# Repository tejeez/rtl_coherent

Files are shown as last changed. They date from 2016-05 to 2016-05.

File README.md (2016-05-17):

rtl_coherent: Synchronized RTL-SDR receivers
============================================

This is a hardware and software project to synchronize multiple RTL-SDR
receivers and make it possible to use them for applications such as
radio direction finding, passive radars, measuring equipment,
radio astronomy interferometers and MIMO communications.

Basic idea
----------

A single 28.8 MHz reference clock is distributed to all dongles. This makes
their sampling rates and local oscillator frequencies equal but doesn't
guarantee that they would actually sample simultaneously or that their
local oscillators would be in the same phase. 

Both the local oscillator phase and sample time offset get a random value
every time the dongles are initialized. This happens because commands don't
arrive to all receivers at exactly the same time and because their frequency
synthesizers are not known to provide a way to reset their phases.

To handle this we have to find the time and phase offsets every time the
receiver is used. This is done by disconnecting receivers from their antennas
and connecting them to a single white noise source. Cross correlating this
noise finds these offsets and lets us correct them. Currently the signal is
recorded in short blocks and each block starts with a burst of noise.

Electronics
-----------

The current hardware prototype has 3 dongles. One of them has the original
28.8 MHz crystal in place and other 2 dongles have the crystal removed. Clock
is distributed from one dongle to crystal pins of the two other dongles
through small capacitors. A better solution for a larger number of dongles
would be to have a separate 28.8 MHz oscillator and distribute it.

The inputs of the dongles are switched between antennas and noise source by
SA630D switches. They are controlled by an RC timing circuit triggered by
I2C clock in the dongles. Every time the R820T tuner chip receives a
command from the RTL2832U chip, there's some activity on the I2C bus.
This switches the inputs to the noise source and the timing circuit keeps
them there for some time after the I2C traffic has finished. The idea is to
have the noise burst triggered every time the center frequency is changed
which should make fast scanning easier.

A crude schematic of simple prototype hardware is now available in
[hardware/simple/](hardware/simple/README.md).

Software
--------

The current software is primarily written for radio direction finding based on
phase difference between elements of an antenna array.

The software records a block of signal from each dongle, cross correlates the
noise in beginning of each block to determine the phase and timing offsets,
corrects for them, divides the signal in narrow frequency bins using FFT and
calculates covariance between each receiver pair for each frequency bin.
Complex argument of an element in the covariance matrix represents the measured
phase difference between two antennas and is used for direction finding.
The same covariance matrix could also be used in more sophisticated direction
finding algorithms such as MUSIC or ESPRIT which might become more useful when
the number of antennas is increased.

rtl_coherent uses features in keenerd's experimental experimental RTL-SDR
branch. Get it from https://github.com/keenerd/rtl-sdr

The software has mostly been developed in Debian Linux on ordinary x86-64 PCs
but many other Linux distributions and architectures should work as well.

Experiments and demonstrations
------------------------------

Direction finding was first tested on 433 MHz amateur radio band using an array
of 3 groundplane antennas spaced by 1/3 wavelength.
See a video here: https://www.youtube.com/watch?v=8Wzb1mgZ0EE

It was also tested on higher HF bands using an array of ground mounted
vertical antennas. A spectrogram from 26.4 MHz to 28.8 MHz where color hue
represents the estimated angle of arrival can be seen here:
http://prkele.prk.tky.fi/~peltolt2/colordf_27600kHz_7h.jpg

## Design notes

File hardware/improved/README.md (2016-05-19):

Schematics and PCB designs for parts of improved hardware.
PCBs have been designed using eagle.

noisesource.sch is the schematic for a better noise source based on three
BGA2803 MMICs. This MMIC was chosen because it has almost flat gain up to
2 GHz, works on 3.3 V and consumes relatively little current. Linearity
and noise figure are not important here.

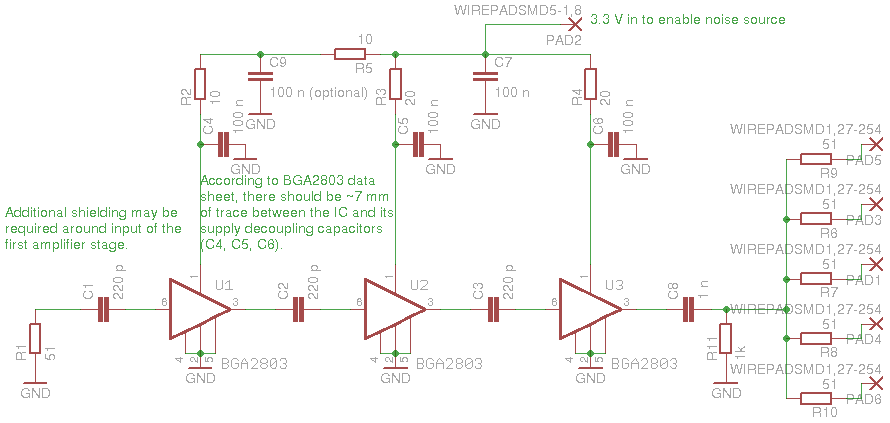
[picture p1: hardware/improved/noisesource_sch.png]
Schematic of noise source


noisesource.brd is a PCB design which has been built on a homemade PCB
and works. The positions of ground vias in the design don't exactly
correspond to what was built. Consider adding more vias near edge of the
board if you decide to order PCBs from somewhere.

The noise source hasn't been tested as a part of the coherent rtl-sdr setup
yet but it should work well and will be tested soon.

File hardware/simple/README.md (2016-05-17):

Hardware for three dongles
==========================

This is the simple hardware with 3 dongles that has been used for most of tests
for now.

One of the dongles has the original 28.8 MHz crystal in place and other 2
dongles have the crystal removed. Clock is distributed from one dongle to
crystal pins of the two other dongles through 10 pF capacitors:
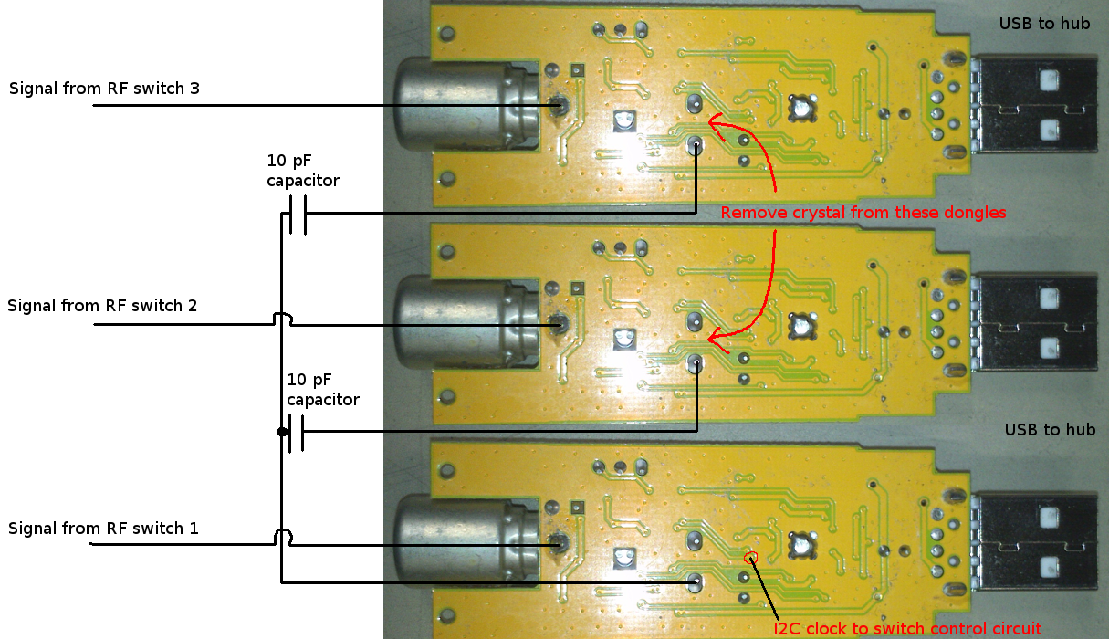
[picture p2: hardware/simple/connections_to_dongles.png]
Connections to dongles


The inputs of the dongles get signal through SA630D switches controlled by a
switch control circuit:
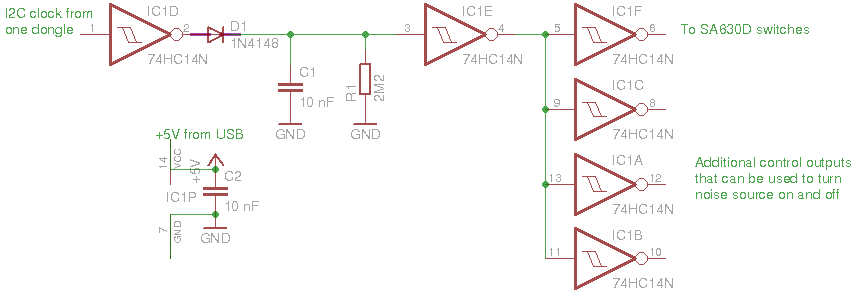
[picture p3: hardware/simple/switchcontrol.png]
Switch control circuit


Here's a schematic of the switch board:
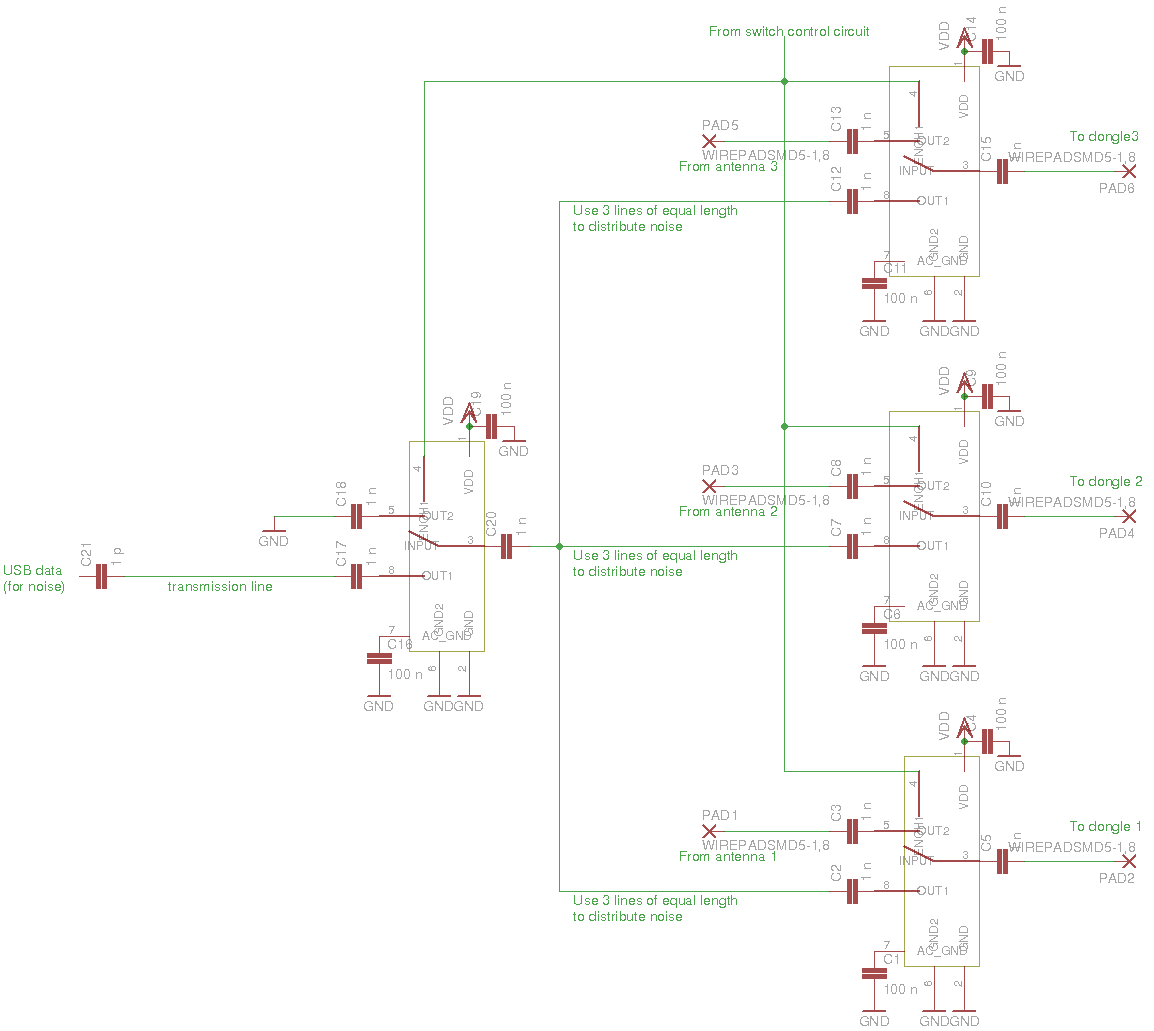
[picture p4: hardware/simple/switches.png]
Switches

(TODO: make it look more clear and learn to properly use some PCB design
software...)

One of USB data lines is used as the noise source.
It's not the best way but somewhat works.

Here's picture of the hardware to help understand how it's actually built:
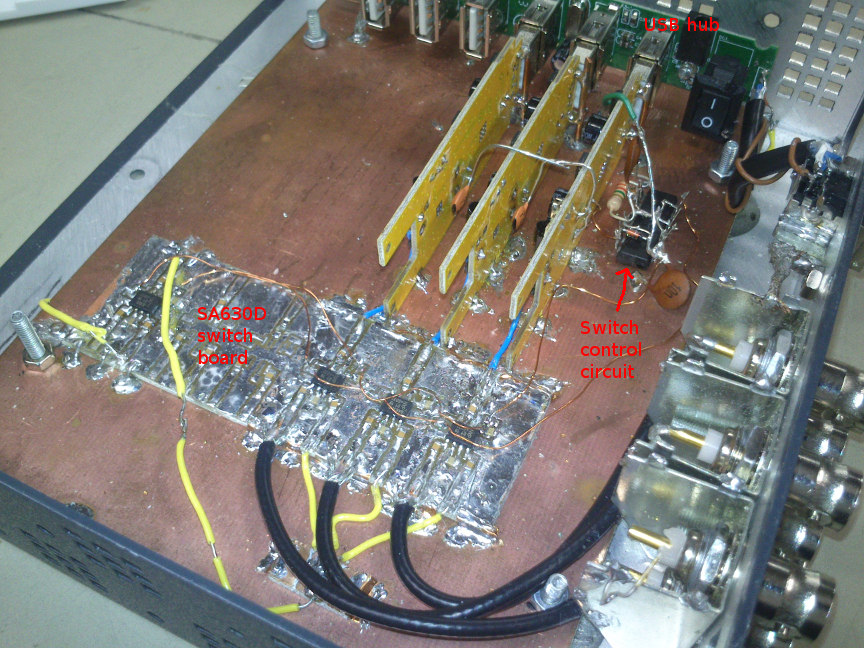
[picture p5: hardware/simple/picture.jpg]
Picture of the hardware


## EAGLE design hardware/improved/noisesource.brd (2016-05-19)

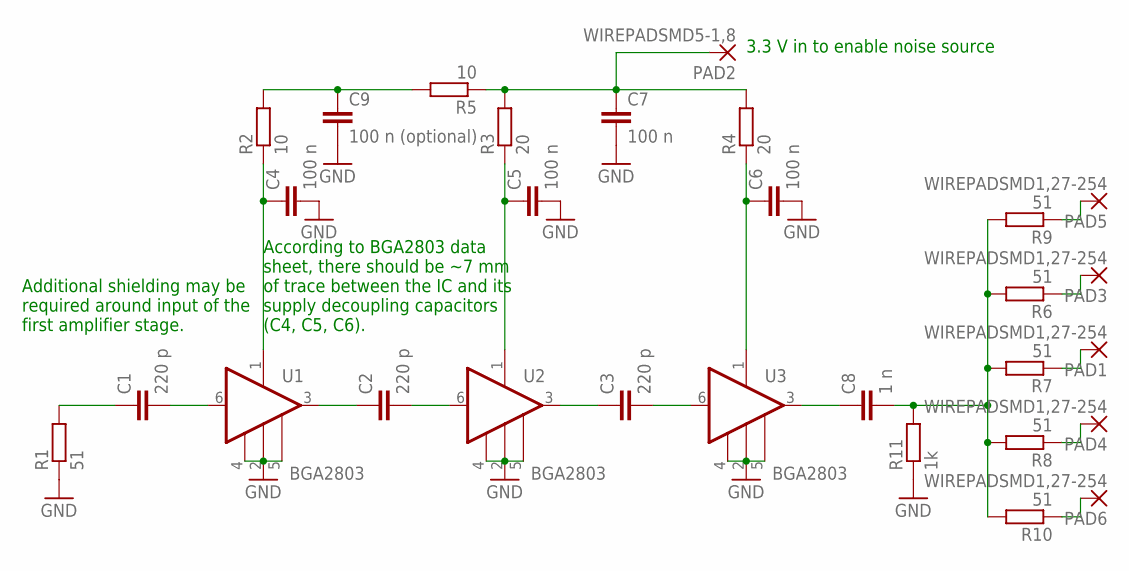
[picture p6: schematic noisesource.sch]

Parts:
C1, C2, C3: 220 p; C0805
C4, C5, C6, C7: 100 n; C0805
C8: 1 n; C0805
C9: 100 n (optional); C0805
PAD1, PAD3, PAD4, PAD5, PAD6: WIREPADSMD1,27-254; SMD1,27-2,54
PAD2: WIREPADSMD5-1,8; 5-1,8
R1, R6, R7, R8, R9, R10: 51; R0805
R2, R5: 10; R0805
R3, R4: 20; R0805
R11: 1k; R0805
U1, U2, U3: BGA2803; SOT363

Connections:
GND: C4.2, C5.2, C6.2, C7.2, C9.2, R1.1, R11.1, U1.2 (GND2), U1.4 (GND1), U1.5 (GND2), U2.2 (GND2), U2.4 (GND1), U2.5 (GND2), U3.2 (GND2), U3.4 (GND1), U3.5 (GND2)
unnamed: C2.1, U1.3 (OUT)
unnamed: C2.2, U2.6 (-IN)
unnamed: C3.1, U2.3 (OUT)
unnamed: C3.2, U3.6 (-IN)
unnamed: C1.1, R1.2
unnamed: C1.2, U1.6 (-IN)
unnamed: C4.1, R2.1, U1.1 (VCC)
unnamed: C5.1, R3.1, U2.1 (VCC)
unnamed: C6.1, R4.1, U3.1 (VCC)
unnamed: C7.1, PAD2.1, R3.2, R4.2, R5.1
unnamed: C8.1, U3.3 (OUT)
unnamed: PAD1.1, R7.1
unnamed: C9.1, R2.2, R5.2
unnamed: PAD3.1, R6.1
unnamed: PAD4.1, R8.1
unnamed: PAD5.1, R9.1
unnamed: PAD6.1, R10.1
unnamed: C8.2, R6.2, R7.2, R8.2, R9.2, R10.2, R11.2

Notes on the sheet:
3.3 V in to enable noise source
According to BGA2803 data sheet, there should be ~7 mm of trace between the IC and its supply decoupling capacitors (C4, C5, C6).
Additional shielding may be required around input of the first amplifier stage.

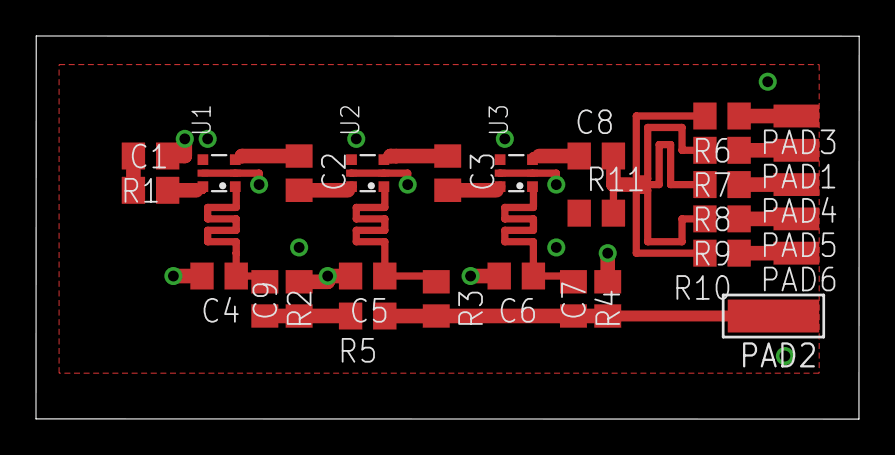
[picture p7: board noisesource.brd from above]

Board: 2 copper layers, 45.7 x 21.3 mm, 29 parts (0 on the bottom side), 19 nets.

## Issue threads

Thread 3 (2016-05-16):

Error

junaid124, 2016-05-16:
/tmp/ccRf0o1P.o: In function `dongle_f':
dongles.c:(.text+0x6c): undefined reference to `rtlsdr_set_dithering'
dongles.c:(.text+0x86): undefined reference to `rtlsdr_set_if_freq'
collect2: error: ld returned 1 exit status
make: *** [main] Error 1

andyn, 2016-05-16:
Are you using Keenerd's experimental branch of rtl-sdr drivers?

junaid124, 2016-05-17:
Hi,
Thanks for your time, No i have installed standard drivers, but after having installed said driver i got following errors 
/Downloads/rtl_coherent-master$ ./run.sh ./run.sh: line 1: ./sdl_waterfall: No such file or directory./run.sh: line 2: ./main: No such file or directoryjunaid@junaid:~/Downloads/rtl_coherent-master$ ./crosscorrelate.py Traceback (most recent call last):  File "./crosscorrelate.py", line 14, in <module>    a = np.fromfile(filename, dtype=np.dtype("u1"))IOError: [Errno 2] No such file or directory: 'd00_b'junaid@junaid:~/Downloads/rtl_coherent-master$ ./inter_df.py Traceback (most recent call last):  File "./inter_df.py", line 6, in <module>    import matplotlib.pyplot as pltImportError: No module named 'matplotlib'junaid@junaid:~/Downloads/rtl_coherent-master$ ./plot_covar.py Traceback (most recent call last):  File "./plot_covar.py", line 6, in <module>    import matplotlib.pyplot as pltImportError: No module named 'matplotlib'///////////////////////////////////////////////////////////////////////////////////////////////////////////////after having installed "sudo apt-get install python3-matplotlib"
gui splash up with error 
FileNotFoundError: [Errno 2] No such file or directory: 'fifo'junaid@junaid:~/Downloads/rtl_coherent-master$ ./crosscorrelate.py  music_df.py        run.sh             inter_df.py        plot_covar.py      junaid@junaid:~/Downloads/rtl_coherent-master$ ./crosscorrelate.py Traceback (most recent call last):  File "./crosscorrelate.py", line 14, in <module>    a = np.fromfile(filename, dtype=np.dtype("u1"))IOError: [Errno 2] No such file or directory: 'd00_b'junaid@junaid:~/Downloads/rtl_coherent-master$ ./plot_covar.py Traceback (most recent call last):  File "./plot_covar.py", line 26, in <module>    with open("fifo") as fifo:FileNotFoundError: [Errno 2] No such file or directory: 'fifo'/////////////////////////////////////////////////////////////////////////////////////////////////
Can you please provide the hardware that you have used for this experiment i would like to buy it.   Regards, 
Muhammad Junaid 
Project Manager Tech 
PMD, NRTC, Haripur, Pakistan 
National Radio & Telecom Corporation - Pakistan
Phone (+92)995-666770 | (+92)3335975856 

    On Monday, May 16, 2016 1:22 PM, Antti <notifications@github.com> wrote:

 Are you using Keenerd's experimental branch of rtl-sdr drivers?—
You are receiving this because you authored the thread.
Reply to this email directly or view it on GitHub

andyn, 2016-05-17:
Running `make` in the directory should create the fifo in addition to compiling the actual binaries. Edit the config file and change the center frequency to something interesting like around 100 MHz, plug in three rtlsdr devices and run the script. You should either get a grayish or colourful waterfall if the program works. Don't bother editing the array geometry until you have built both an antenna array and the antenna calibration switch board.

A schema will probably be drawn & released in a few weeks. You'll need at least Schmitt triggers to tap the I2C line and solid state RF switches to connect the dongles to a single noise source (the USB data wires work surprisingly well for lower frequencies).

The antenna hardware is mostly made of copper wire, ferrite, PVC pipe, epoxy, aluminum plate and hose clamps. It makes no sense to ship it around the world. ;-)

chenhaimeng, 2017-10-23:
`root@ubuntu:/home/hmchen/Downloads/rtl_coherent# make
gcc dongles.c main.c synchronize.c correlate.c configuration.c df.c -o main -Wall -Wextra -O3 -lm -ffast-math -lrtlsdr -lpthread -lfftw3f
dongles.c: In function ‘dongle_f’:
dongles.c:46:9: warning: implicit declaration of function ‘rtlsdr_set_dithering’ [-Wimplicit-function-declaration]
  CHECK1(rtlsdr_set_dithering(dev, 0));
         ^
dongles.c:23:16: note: in definition of macro ‘CHECK1’
  int retval = (x); \
                ^
dongles.c:47:9: warning: implicit declaration of function ‘rtlsdr_set_if_freq’ [-Wimplicit-function-declaration]
  CHECK1(rtlsdr_set_if_freq(dev, conf.if_freq));
         ^
dongles.c:23:16: note: in definition of macro ‘CHECK1’
  int retval = (x); \
                ^
/tmp/cczi2yRh.o: In function `dongle_f':
dongles.c:(.text+0x7a): undefined reference to `rtlsdr_set_dithering'
dongles.c:(.text+0x94): undefined reference to `rtlsdr_set_if_freq'
collect2: error: ld returned 1 exit status
Makefile:9: recipe for target 'main' failed
make: *** [main] Error 1
root@ubuntu:/home/hmchen/Downloads/rtl_coherent# df -h
Filesystem      Size  Used Avail Use% Mounted on
udev            465M     0  465M   0% /dev
tmpfs            98M  7.4M   90M   8% /run
/dev/sda1        19G  5.2G   13G  30% /
tmpfs           486M  312K  486M   1% /dev/shm
tmpfs           5.0M  4.0K  5.0M   1% /run/lock
tmpfs           486M     0  486M   0% /sys/fs/cgroup
tmpfs            98M   88K   98M   1% /run/user/1000
root@ubuntu:/home/hmchen/Downloads/rtl_coherent#`

andyn, 2017-10-23:
Again, install [Keenerd's experimental branch](https://github.com/keenerd/rtl-sdr) drivers and recompile.

The amount of disk space has nothing to do with this issue whatsoever. If you're having other problems, post a new bug report.

chenhaimeng, 2017-10-24:
step：
1：clone https://github.com/keenerd/rtl-sdr.git
  cd rtl-sdr
  mkdir build
  cd build
  cmake ..
  make
  sudo make install
  sudo ldconfig

2：clone  https://github.com/tejeez/rtl_coherent.git
  make
dongles.c:(.text+0x7a): undefined reference to rtlsdr_set_dithering' dongles.c:(.text+0x94): undefined reference tortlsdr_set_if_freq'
collect2: error: ld returned 1 exit status
Makefile:9: recipe for target 'main' failed
make: *** [main] Error 1

thefez, 2018-02-09:
Has anyone found a solution to this problem yet? I'm also experiencing this problem despite installing keenerd and tejeez's repos.

`odroid@odroid:~/Downloads/rtl_coherent$ make
gcc dongles.c main.c synchronize.c correlate.c configuration.c df.c -o main -Wall -Wextra -O3 -lm -ffast-math -lrtlsdr -lpthread -lfftw3f
/tmp/cccDDRG3.o: In function `dongle_f':
dongles.c:(.text+0x6a): undefined reference to `rtlsdr_set_dithering'
dongles.c:(.text+0x78): undefined reference to `rtlsdr_set_if_freq'
collect2: error: ld returned 1 exit status
Makefile:9: recipe for target 'main' failed
make: *** [main] Error 1
`

tejeez, 2018-02-12:
Maybe you still have some other version of librtlsdr installed in another path. Things you could check and try:
- Did you remember to run `ldconfig` after installing rtl-sdr?
- Try `whereis librtlsdr` and see if it gives the path where you installed it (usually /usr/local/lib/librtlsdr.so by default).
- `export LD_LIBRARY_PATH=/usr/local/lib` before compiling and running rtl_coherent might help but is usually not needed.
- If you've installed rtl-sdr from your package manager, uninstall it if possible. This is not usually necessary though and might also uninstall some other programs that depend on it.

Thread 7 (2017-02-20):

PCB of Antenna Switch and Noise source?

E3V3A, 2017-02-20:
Hi Tatu!
What a great project! However, the antenna switch PCB (or whatever it is on that picture) is very unclear. *Do you have any CAD of that or do you know of any?* I think your design with the new noise source would be a great project for a complete small box design, possibly improving performance by more exact traces etc. I'd be happy to contribute to such a design project if you are still interested.

E3V3A, 2018-01-09:
https://github.com/tejeez/rtl_coherent/blob/master/hardware/simple/README.md

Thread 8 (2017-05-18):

documentation

pti13, 2017-05-18:
Hello,
I am trying to use this software to sync my 2 haked RTL receivers.
I can see that is is build and configured specifically for project that is described in README.
How I can use it, just to sync receivers and run rtl_tcp?

Thanks in advanced.

tejeez, 2017-05-18:
Do you want a server that works like rtl_tcp but provides two synchronized signals instead? You could remove the calls to the part that does direction finding (corr_block) and send the samples to a TCP socket instead. See here: https://github.com/tejeez/rtl_coherent/blob/39ea2f1814fbb5e6469f5794dba393431d88f7ae/main.c#L40
Note that it can already write the samples to a file if you give W as the second command line argument. You could that from there.

Note that rtl_coherent works in short blocks of samples so you don't get a continuous stream. You also need the circuit to switch a noise source to the RF inputs at start of each block.

rtl_coherent was never really designed to be easily usable for purposes other than demonstrating that synchronization is possible. I've been working on a totally rewritten (possibly but not yet gnuradio based) version that would more easily provide a continuous stream of synchronized samples to other applications.

pti13, 2017-05-26:
Thanks a lot,
I will try to do it.

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

--
Sent from my Gmail.

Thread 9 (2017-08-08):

Direction Finding Usage Documentation

flatflyfish, 2017-08-08:
Got it running with ./run.sh, but how do we use your inter_df and music_df Python files? Trying to set up something similar to what you have in your video.

andyn, 2017-08-09:
Use the phase comparison interferometer, forget about the MUSIC one. It would require more receiver channels and extra calibration to work reliably.

The `main` binary writes the channel correlation matrix into a POSIX pipe named `fifo`. The direction finder programs consume the data from there and do the actual angle of arrival estimation.

First fire up the consumer program, like inter_df.py. Opening the pipe will block until it gets data. Then, in another terminal run the main binary, and everything should work.

I can't emphasize enough that this is a proof-of-concept demo that requires rtl-sdr hacker skills and proper antenna switch hardware, not just three dongles with the stock antennas. That's also why the written documentation isn't that good – it's expected that you actually know what you're doing.

flatflyfish, 2017-08-09:
Thanks, yep I understand it's all proof of concept and the HW requirements. I want to learn about DF and this seems like a good start. A little more documentation wouldn't hurt though! :)

Hmm I had to go back to an earlier version to get inter_df.py to work though. The latest version causes a crash and makes ./main disconnect from the dongles.

andyn, 2017-08-09:
I'll borrow the original hardware from @tejeez tomorrow and try to find out why the interferometer crashes. I probably won't add any features on the program, though.

tejeez, 2017-08-09:
The reason is the format and contents of the data moved in the pipe were completely changed when direction finding was implemented in C code. When the inter_df script was used, the C program printed covariance matrix of the strongest signal (frequency bin with most power) in text format in pipe and the python script calculated the DOA from that. Now, the C program calculates DOA for all frequencies and sends them in binary format for the waterfall program to draw. This means inter_df doesn't currently work at all without some changes to code.

Sending the matrix in text format is still left in the code inside #if 0 and might work if you change it to # if 1:
https://github.com/tejeez/rtl_coherent/blob/master/correlate.c#L136

Try to make another pipe (mkfifo fifo2) and change its file name there at line 139 and in inter_df line 73. That way you could have both the waterfall and the python script running at the same time.

andyn, 2017-08-10:
Yup, seems like inter_df.py has been written for the earlier data format. Try the SDL waterfall program instead. You can launch it via `run.sh`.

- It's looks much nicer than a Numpy polar plot
- You're able to DF a whole 2 MHz wide block of spectrum instead of a narrow band frequency
- You'll instantly see if the calibration works and if there are strong interfering signals that prevent synchronization.

If you need a more accurate direction-of-arrival indication, you can hack the waterfall program to e.g. show the (Frequency, DoA) coordinates of the mouse cursor.

flatflyfish, 2017-08-10:
Thanks I'll take a look at the code for both.

One thing I didn't quite get. What is the bottom pane in sdl_waterfall showing?

Is it the spectrum of the current block, including the noise sync block? I guess it's meant to show a short burst of noise near the bottom, and then the signals further up?

I'm going to try and use the GPIO to switch in and out the noise source with timing done in software instead of via the RC circuit.

andyn, 2017-08-10:
The frequency is on the X axis and the angle of arrival is on the Y axis.
The amplitude shows the strength of the correlation, so you should usually
see greenish blob near the most probable direction of arrival.

Wideband local QRM usually has multiple DoA results that point in the same
direction, so the lower half of the display should also help you visually
eliminate noninteresting results.

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

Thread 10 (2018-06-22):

Direction finding doesn't seem to work

jacobstein123, 2018-06-22:
I have the hardware all built (with the noise / signal switching working and the shared clock), and your code detects all three dongles and seems to run successfully, but in the waterfall visualization there is no green blob corresponding to the angle of arrival. It  seems like it's just a green vertical bar of dots which doesn't correspond to any specific angle. I'm using three antennas in the same orientation (and almost the same distance from each other) as your pizzabox setup, and I've updated all the coordinates to reflect my setup. Even after I got the inter_df.py compass script working, it just jumps all over the place instead of showing one direction.

Do you have any advice for how I can get it working? Thanks!

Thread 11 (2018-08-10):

Using simple hardware, where the "USB data(for noise)" connects to?

w79110007, 2018-08-10:
Hi tejeez,
I am trying to implement it myself, but I don't understand where the "USB data(for noise)" on the switch board will connect to. It seems it will connect to a noise source, so where is the noise source schematic? Is it connected to another port of USB hub?

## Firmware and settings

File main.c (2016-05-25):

#include "configuration.h"
#include "dongles.h"
#include "synchronize.h"
#include "correlate.h"
#include "df.h"
#include <signal.h>
#include <stdlib.h>
#include <time.h>
#include <unistd.h>

int ndongles = 0, blocksize = 0, nbuffers = 0;
int di;
int readfromfile = 0, writetofile = 0, writetofile2 = 0;
samples_t **buffers;
FILE **files, **files2;


volatile int do_exit = 0;
static void sighandler(int signum) {
	(void)signum;
	do_exit = 1;
}
static void initsignals() {
	struct sigaction sigact;
	sigact.sa_handler = sighandler;
	sigemptyset(&sigact.sa_mask);
	sigact.sa_flags = 0;
	sigaction(SIGINT, &sigact, NULL);
	sigaction(SIGTERM, &sigact, NULL);
	sigaction(SIGQUIT, &sigact, NULL);
	sigaction(SIGPIPE, &sigact, NULL);
}


static int dodsp(int blocksize, void **buffers) {
	int nsamples = 0;
	int di;
	csample_t *bufs[NRECEIVERS_MAX];
	float fracdiffs[NRECEIVERS_MAX], phasediffs[NRECEIVERS_MAX];
	sync_blockp(blocksize / sizeof(csample_t), (csample_t**)buffers, &nsamples, bufs, fracdiffs, phasediffs);
	if(writetofile2) {
		for(di = 0; di < ndongles; di++) {
			fwrite(bufs[di], nsamples*sizeof(**bufs), 1, files2[di]);
		}
	}
	corr_block(nsamples, bufs, fracdiffs, phasediffs);
	return 0;
}



/*
DSP and dongle control are done in separate threads to make it possible to be
reading the next block while the previous block is being processed.
There's a simple lockless queue between the threads.
*/
static volatile int nbuf_write=0, nbuf_read=0;
pthread_t dspthread;

static void *dspthread_f(void *arg) {
	int nbuf_r = nbuf_read;
	(void)arg;
	while(!do_exit) {
		while(nbuf_r != nbuf_write) { /* data waiting in buffers? */
			dodsp(blocksize, (void**)(buffers + ndongles * nbuf_r));
			if(writetofile) {
				for(di = 0; di < ndongles; di++) {
					fwrite(buffers[di], blocksize, 1, files[di]);
				}
			}
			nbuf_read = nbuf_r = (nbuf_r + 1) % nbuffers;
		}
		usleep(100000); /* TODO: proper synchronization */
	}
	return NULL;
}


int main(int argc, char *argv[]) {
	int timestamp = time(NULL);
	int i;
	/* TODO: properly parse command line arguments */
	if(argc >= 3) {
		if(argv[2][0] == 'r' && argc >= 4) {
			readfromfile = 1;
			timestamp = atoi(argv[3]);
		}
		if(argv[2][0] == 'w')
			writetofile = 1;
		if(argv[2][0] == 'W' || argv[2][1] == 'W')
			writetofile2 = 1;
	}
	initsignals();
	conf_read(argv[1]);
	for(i = 2; i < argc; i++) {
		if(argv[i][0] == 'c') conf.calibrationmode = 1;
	}
	
	/* TODO: get rid of these and make all the code read the configuration struct? */
	ndongles = conf.nreceivers;
	nbuffers = conf.nbuffers;
	blocksize = conf.blocksize;

	sync_init();
	corr_init();
	if(!conf.calibrationmode) df_init();

	buffers = malloc(nbuffers * ndongles * sizeof(*buffers));
	files = malloc(ndongles * sizeof(*files));
	files2 = malloc(ndongles * sizeof(*files2));
	
	for(di=0; di < ndongles * nbuffers; di++)
		buffers[di] = malloc(blocksize * sizeof(**buffers));
	
	for(di=0; di < ndongles; di++) {
		char t[32];
		if(readfromfile || writetofile) {
			sprintf(t, "d%02d_%d", di, timestamp);
			if((files[di] = fopen(t, readfromfile ? "rb" : "wb")) == NULL) {
				fprintf(stderr, "Could not open file\n");
				goto fail;
			}
		}
		if(writetofile2) {
			sprintf(t, "c%02d_%d", di, timestamp);
			if((files2[di] = fopen(t, "wb")) == NULL) {
				fprintf(stderr, "Could not open file2\n");
				goto fail;
			}
		}
	}
	if(readfromfile) {
		for(;;) {
			for(di = 0; di < ndongles; di++) {
				if(fread(buffers[di], blocksize, 1, files[di]) == 0)
					goto fail;
			}
			dodsp(blocksize, (void**)buffers);
		}
	} else {
		int donglesok = coherent_init(ndongles);
		pthread_create(&dspthread, NULL, dspthread_f, NULL);

		if(donglesok == ndongles) {
			while(do_exit == 0) {
				int nbuf_write_next = (nbuf_write + 1) % nbuffers;
				if(nbuf_write_next != nbuf_read) { /* buffers free? */
					if(coherent_read(blocksize, buffers + ndongles * nbuf_write) == -1) break;
					nbuf_write = nbuf_write_next;
				} else {
					fprintf(stderr,"\rBuffer overflow!");
					usleep(100000); /* TODO: proper synchronization */
				}

			}
		}
		coherent_exit();

		pthread_kill(dspthread, SIGINT);
		pthread_join(dspthread, NULL);

	}
	fail:
	sync_exit();
	return 0;
}

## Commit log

2015-06-29 Implement switch control
2015-07-02 Calculate fractional sample delay
2015-07-11 Workaround for hardware problems etc
    [main.c]
2015-10-17 Print covariance matrix for testing
2015-10-18 Skip first samples for synchronization, change some pointer types
    [main.c]
2015-10-31 Bugfix in 'plot_covar.py': matplotlib calls updated, printing prettyfied
2015-12-30 Configuration file and cable skew correction
    [configuration.h]
2016-01-02 Put DSP and dongle control in separate threads
    [configuration.h]
2016-05-05 Read antenna positions from configuration file
    [configuration.h]
2016-05-17 Added schematic
    [switchcontrol.sch, switches.sch]
2016-05-19 Added design for improved noise source
    [noisesource.brd, noisesource.sch]
2016-05-25 Added calibration mode enabled by command line argument
    [configuration.h]
